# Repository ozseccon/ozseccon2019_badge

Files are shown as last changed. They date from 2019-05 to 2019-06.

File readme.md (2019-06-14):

# OzSecCon 2019 badge design.
designed in kicad v4
FW developed using (embedded rust)[https://rust-embedded.github.io].

# Instructions for use
## Using the badge
Bottom Button plays track
Top Button is to change track

Long press on Top to change card
Long press on Bottom to exit magspoof mode
(i was going to make a pattern thing appear but ran out of time)

## Loading new cards
card program is present at 
    ./ozseccon2019_utility/cardutil.py

Cards are formatted as a JSON file
Badge uses USB HID to communication.
i've only used ubuntu 14.04 to test so YMMV.

python libs used are:
hid
time
argparse
json

1. Leave battery in.
1. CAREFULLY insert a USB micro cable.
1. check that it enumerates
    \#lsusb
    004 Device 001: ID 1d6b:0003 Linux Foundation 3.0 root hub
    Bus 003 Device 107: ID ffff:ffff  
    Bus 003 Device 001: ID 1d6b:0002 Linux Foundation 2.0 root hub
you should see ID ffff:ffff show up.
1. run cardutil as root - this is due to using USB YMMV
```
    ozseccon2019_utility$ sudo python ./cardutil.py --cardfile ./carddata.json 
    ________             _________              _________                   
    \_____  \  ________ /   _____/  ____   ____ \_   ___ \   ____    ____   
     /   |   \ \___   / \_____  \ _/ __ \_/ ___\/    \  \/  /  _ \  /    \  
    /    |    \ /    /  /        \  ___/\  \___\     \____(  <_> )|   |  \ 
    \_______  //_____ \/_______  / \___  >\___  >\______  / \____/ |___|  / 
            \/       \/        \/      \/     \/        \/              \/  

    ________ _______   ____  ________  
    \_____  \   _  \ /_   |/   __   \ 
     /  ____//  /_\  \ |   |\____    / 
    /       \  \_/   \|   |   /    /  
    \_______ \_____  /|___|  /____/   
            \/      \/                 

    _________                     .___.____                       .___               
    \_   ___ \ _____  _______   __| _/|    |     ____ _____     __| _/ ____ _______  
    /    \  \/ \__  \ \_  __ \ / __ | |    |    /  _ \__  \   / __ |_/ __ \_  __ \ 
    \     \____ / __ \_|  | \// /_/ | |    |___(  <_> )/ __ \_/ /_/ |\  ___/ |  | \/ 
     \______  /(____  /|__|   \____ | |_______ \____/(____  /\____ | \___  >|__|    
            \/      \/             \/         \/           \/      \/     \/         
    usage: sudo python ./cardutil.py --cardfile [json formatted card file]
    [*] loading cards from ./carddata.json
    [*] loading card 1:
    [*] track1: %B4444444444444444^ABE/LINCOLN^291110100000931?D
    [*] track2: ;4444444444444444=29111010000093100000?9
    [*] track3: 000000000000000000000000000
    [*] loading card 2:
    [*] track1: %B1234567890123445^PADILLA/L.                ^9901120000000000000055123888888?~
    [*] track2: ;1234567890123445=99011200XXXX00000000?*
    [*] track3: ;011234567890123445=72472410000000000003030033040400099010=4320943290432==1=0000000000000000??
    [*] loading card 3:
    [*] track1: %B4888603170607238^Head/Potato^050510100000000001203191805191000000?
    [*] track2: ;4888603170607238=05051011203191805191?
    [*] track3: ;1337?
    Manufacturer: OzSecCon.
    Product: MagSpoof
    Serial No: 1.0.0
    Closing the device
    [*] finished

    ./ozseccon2019_utility/cardutil.py
```
1. You should now be able to use it.

## reprogramming.
Convert file using the (elf2dfuse utility)[https://github.com/majbthrd/elf2dfuse]

1. Short J3 to get device into bootloader mode
1. reset - you should see the two LEDS light up 
1. check that DFU mode, should see ID 0483:df11
    peter@peter-ThinkPad-X230:/media/peter/VM Images/ozseccon2019/ozseccon2019_badge$ lsusb
    Bus 003 Device 119: ID 0483:df11 STMicroelectronics STM Device in DFU Mode
1. check that dfu-util detects board
```
    ~/src/elf2dfuse$ sudo dfu-util -l
    enter sudo password 
    dfu-util 0.8
    
    Copyright 2005-2009 Weston Schmidt, Harald Welte and OpenMoko Inc.
    Copyright 2010-2014 Tormod Volden and Stefan Schmidt
    This program is Free Software and has ABSOLUTELY NO WARRANTY
    Please report bugs to dfu-util@lists.gnumonks.org
    
    Found DFU: [0483:df11] ver=2200, devnum=123, cfg=1, intf=0, alt=1, name="@Option Bytes  /0x1FFFF800/01*016 e", serial="FFFFFFFEFFFF"
    Found DFU: [0483:df11] ver=2200, devnum=123, cfg=1, intf=0, alt=0, name="@Internal Flash  /0x08000000/032*0001Kg", serial="FFFFFFFEFFFF"
    Found Runtime: [0a5c:21e6] ver=0112, devnum=4, cfg=1, intf=3, alt=0, name="UNKNOWN", serial="083E8EE37645"
```
1. use alt 0 - internal flash and program your DFU file
```
    ~/src/elf2dfuse$ sudo dfu-util -d 0483:df11 -a 0 -D ./final.dfu 
    dfu-util 0.8
    
    Copyright 2005-2009 Weston Schmidt, Harald Welte and OpenMoko Inc.
    Copyright 2010-2014 Tormod Volden and Stefan Schmidt
    This program is Free Software and has ABSOLUTELY NO WARRANTY
    Please report bugs to dfu-util@lists.gnumonks.org
    
    Opening DFU capable USB device...
    ID 0483:df11
    Run-time device DFU version 011a
    Claiming USB DFU Interface...
    Setting Alternate Setting #0 ...
    Determining device status: state = dfuERROR, status = 10
    dfuERROR, clearing status
    Determining device status: state = dfuIDLE, status = 0
    dfuIDLE, continuing
    DFU mode device DFU version 011a
    Device returned transfer size 2048
    DfuSe interface name: "Internal Flash  "
    file contains 1 DFU images
    parsing DFU image 1
    image for alternate setting 0, (2 elements, total size = 12780)
    parsing element 1, address = 0x08000000, size = 12052
    Download    [=========================] 100%        12052 bytes
    Download done.
    parsing element 2, address = 0x08002f20, size = 712
    Download    [=========================] 100%          712 bytes
    Download done.
    done parsing DfuSe file
 ```
 
# Stuff i stole/copied from to make this badge
[Samy Kamkar's Magspoof](http://samy.pl/magspoof/)

[RyscCorp's version](https://github.com/RyscCorp/magspoof_r3)

[Aleh Zasypkin Awesome Kroneum project](https://github.com/azasypkin/kroneum)

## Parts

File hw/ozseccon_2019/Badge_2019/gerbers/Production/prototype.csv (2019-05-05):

Id | Designator | Package | Quantity | Designation | Supplier and ref
1 | AE1 | Antenna | 1 | Antenna_Loop
2 | C1 | CP_Elec_6.3x5.7 | 1 | 100uF
3 | C2,C4,C5 | C_0805 | 3 | 100nF
4 | C3 | C_0805 | 1 | 10nF
5 | C6 | C_0805 | 1 | 1uF
6 | C7,C8 | C_0805 | 2 | 4.7uF
7 | D1 | LED_RGB_5050-6 | 1 | LED1
8 | D2 | LED_RGB_5050-6 | 1 | LED2
9 | J1 | BoldPort_Pin_Header_Straight_1x07_Pitch2.54mm | 1 | Conn_01x07_Female
10 | J2 | Pin_Header_Straight_1x04_Pitch2.54mm | 1 | SWD
11 | J3 | Pin_Header_Straight_1x02_Pitch2.54mm | 1 | BOOT0
12 | J4 | Pin_Header_Straight_1x02_Pitch2.54mm | 1 | nRST
13 | J5 | Pin_Header_Straight_2x05_Pitch2.54mm | 1 | LSAO
14 | J6 | USB_Micro-B_Molex-105017-0001 | 1 | USB_MICRO
15 | R1 | R_0805 | 1 | 10k
16 | R2,R3 | R_0805 | 2 | 22
17 | SW1,SW2 | TactSwitch | 2 | SW_DPST_OZSECCON
18 | U1 | ICC_FOOTPRINT | 1 | ICC_Pads
19 | U2 | SOIC-8_3.9x4.9mm_Pitch1.27mm | 1 | TC4424A
20 | U3 | OzSecCon_LQFP-48_7x7mm_Pitch0.5mm | 1 | STM32F042C6T6
21 | BT1 | Keystone_3034_1x20mm-CoinCell | 1 | Battery_Cell
22 | FID1,FID2,FID3 | Fiducial_0.5mm_Dia_1mm_Outer | 3 | Fiducial
23 |  | skully | 1
24 |  | Privasec | 1
25 | REF** | Board_Outline | 1 | Board_Outline

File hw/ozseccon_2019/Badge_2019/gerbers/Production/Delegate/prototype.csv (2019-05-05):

Id | Designator | Package | Quantity | Designation | Supplier and ref | Datasheet | Substitute with lower cost | Extra Components
1 | C1 | CP_Elec_6.3x5.7 | 1 | 100uF | MCVVT016M101EA1L | http://www.farnell.com/datasheets/2151198.pdf | Y | 30
2 | C2,C4,C5 | C_0805 | 3 | 100nF |  |  | Y | 30
3 | C3 | C_0805 | 1 | 10nF |  |  | Y | 30
4 | C6 | C_0805 | 1 | 1uF |  |  | Y | 30
5 | C7,C8 | C_0805 | 2 | 4.7uF |  |  | Y | 30
6 | D1, D2 | LED_RGB_5050-6 | 2 | Yuan Lei LED SMD 5050 RGB | Yuan Lei LED SMD 5050 RGB |  | Y | 30
7 | J6 | USB_Micro-B_Molex-105017-0001 | 1 | USB_MICRO | Multicomp MC001009/ USB Micro B |  | Y | 30
8 | R1 | R_0805 | 1 | 10k |  |  | Y | 30
9 | R2,R3 | R_0805 | 2 | 22 |  |  | Y | 30
10 | SW1,SW2 | TactSwitch | 2 | SW_DPST_OZSECCON | https://www.altronics.com.au/p/s1112a-spst-momentary-smd-4.3mm-tactile-switch/ |  | Y | 30
11 | U2 | SOIC-8_3.9x4.9mm_Pitch1.27mm | 1 | TC4424A | TC4424AVOA713 | http://www.farnell.com/datasheets/512945.pdf | N | 30
12 | U3 | OzSecCon_LQFP-48_7x7mm_Pitch0.5mm | 1 | STM32F042C6T6/STM32 48 pin LQFP, 32kb Flash, 6kb RAM | https://au.element14.com/stmicroelectronics/stm32f042c6t6/mcu-arm-cortex-m0-48mhz-lqfp-48/dp/2750630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 | http://www.farnell.com/datasheets/2281753.pdf | N | 30
13 | BT1 | Keystone_3034_1x20mm-CoinCell | 1 | Battery_Cell | 3034 - BATTERY CONTACT, COIN CELL, 20MM | https://au.element14.com/keystone/3034/battery-contact-coin-cell-20mm/dp/2959377?st=keystone%203034 | Y | 30

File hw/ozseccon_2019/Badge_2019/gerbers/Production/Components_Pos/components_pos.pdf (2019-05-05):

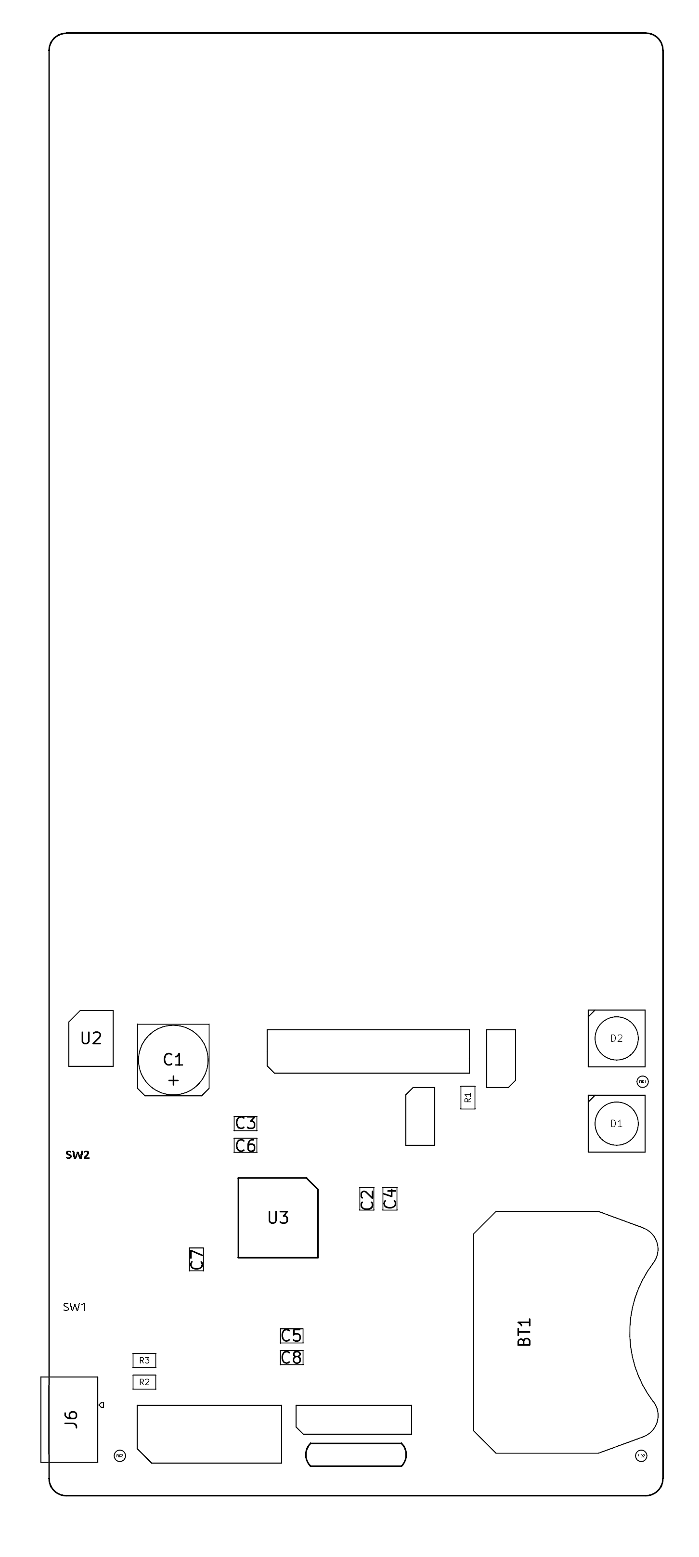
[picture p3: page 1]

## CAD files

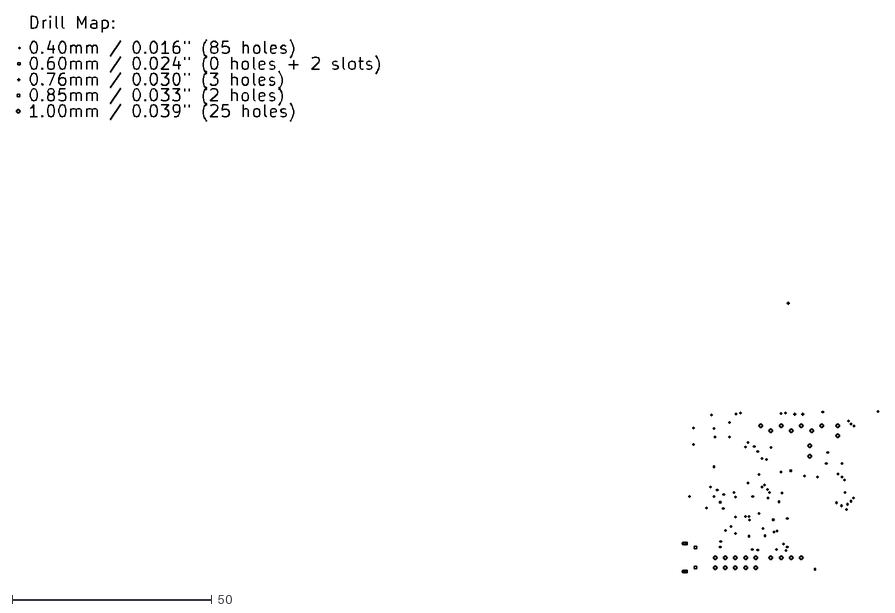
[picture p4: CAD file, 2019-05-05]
hw/ozseccon_2019/Badge_2019/gerbers/Production/Delegate/prototype-drl_map.dxf
216.0 x 139.3

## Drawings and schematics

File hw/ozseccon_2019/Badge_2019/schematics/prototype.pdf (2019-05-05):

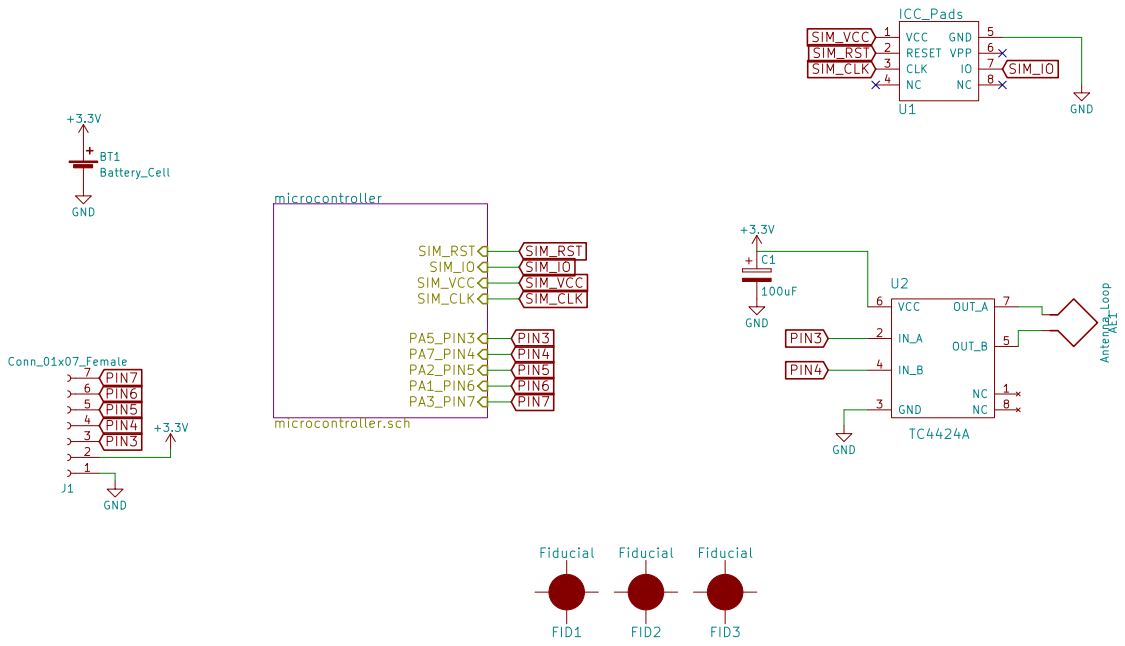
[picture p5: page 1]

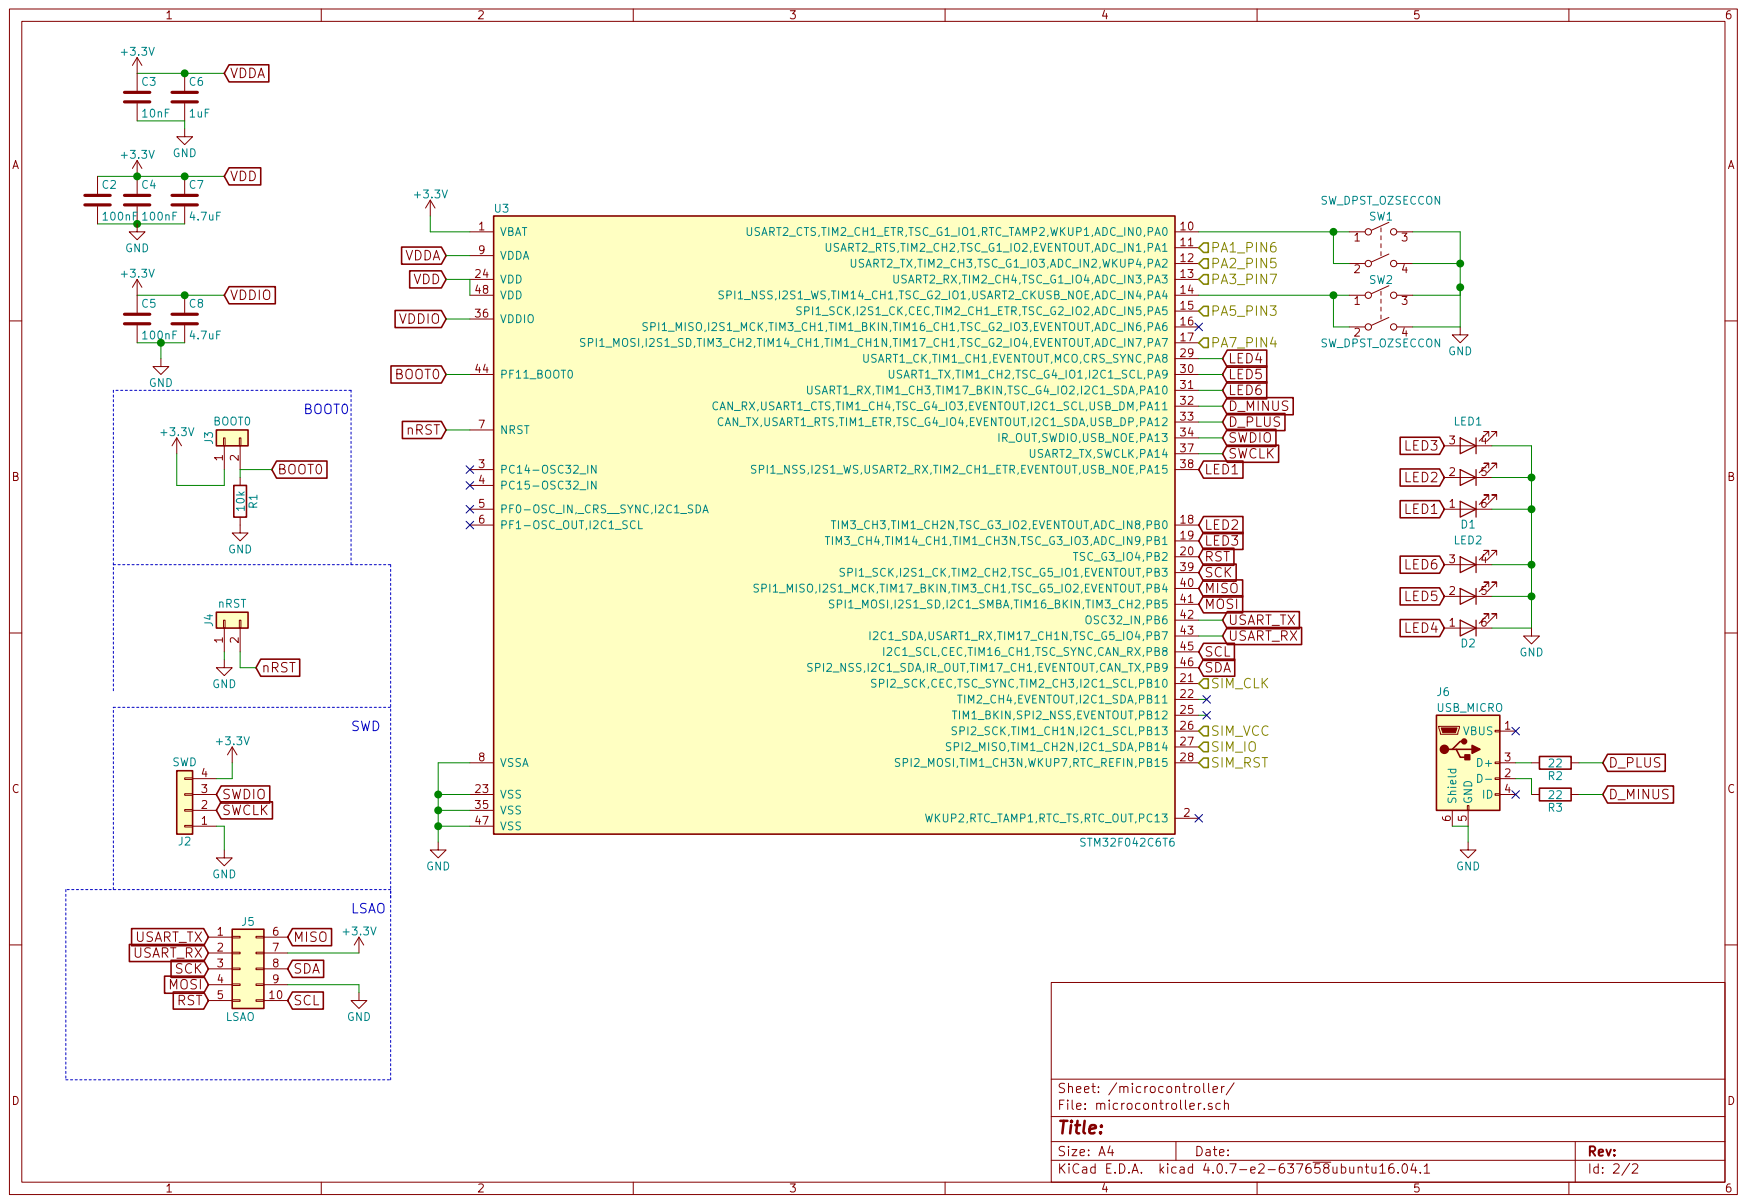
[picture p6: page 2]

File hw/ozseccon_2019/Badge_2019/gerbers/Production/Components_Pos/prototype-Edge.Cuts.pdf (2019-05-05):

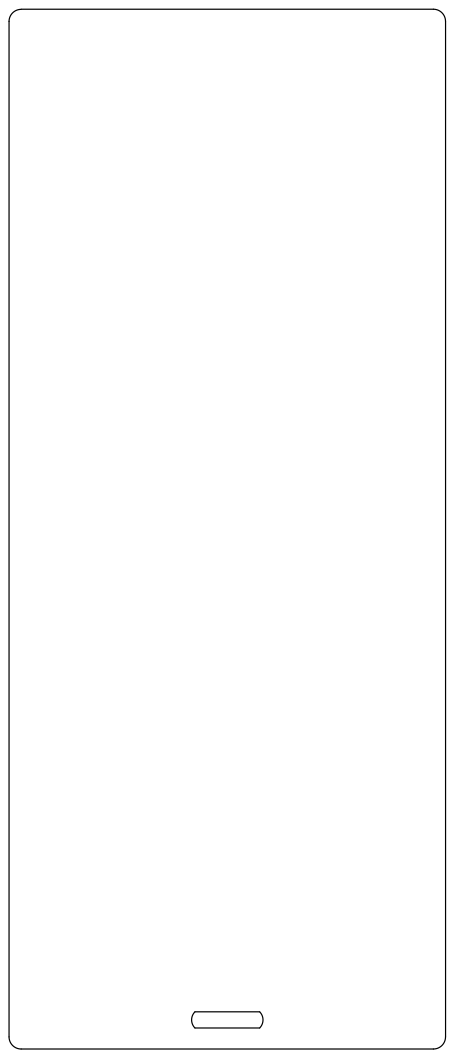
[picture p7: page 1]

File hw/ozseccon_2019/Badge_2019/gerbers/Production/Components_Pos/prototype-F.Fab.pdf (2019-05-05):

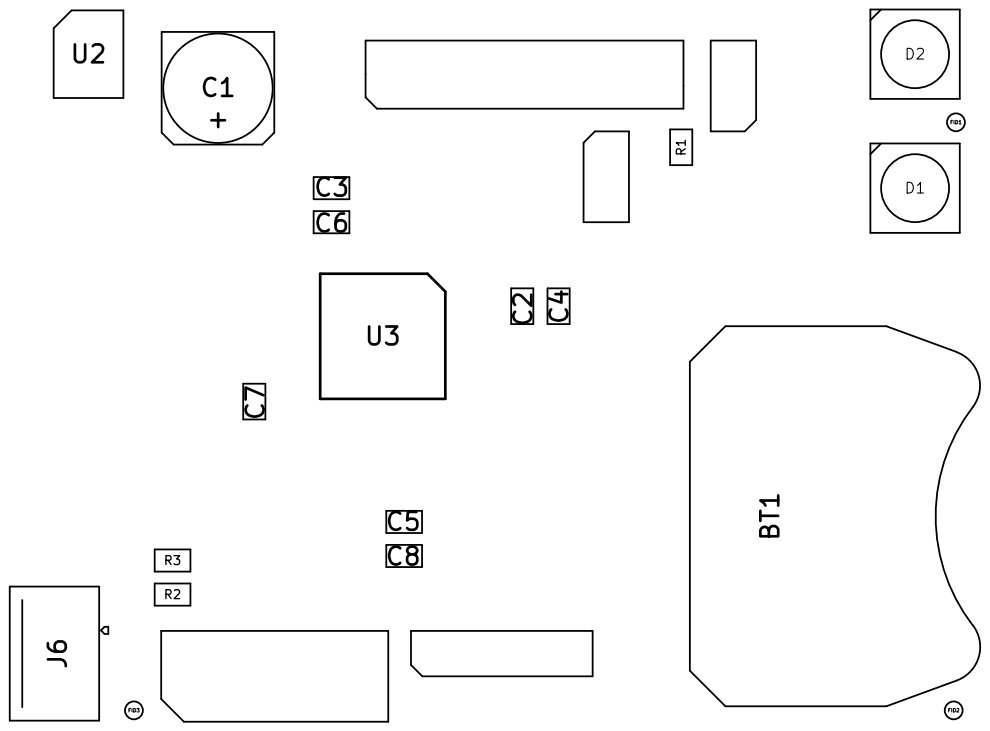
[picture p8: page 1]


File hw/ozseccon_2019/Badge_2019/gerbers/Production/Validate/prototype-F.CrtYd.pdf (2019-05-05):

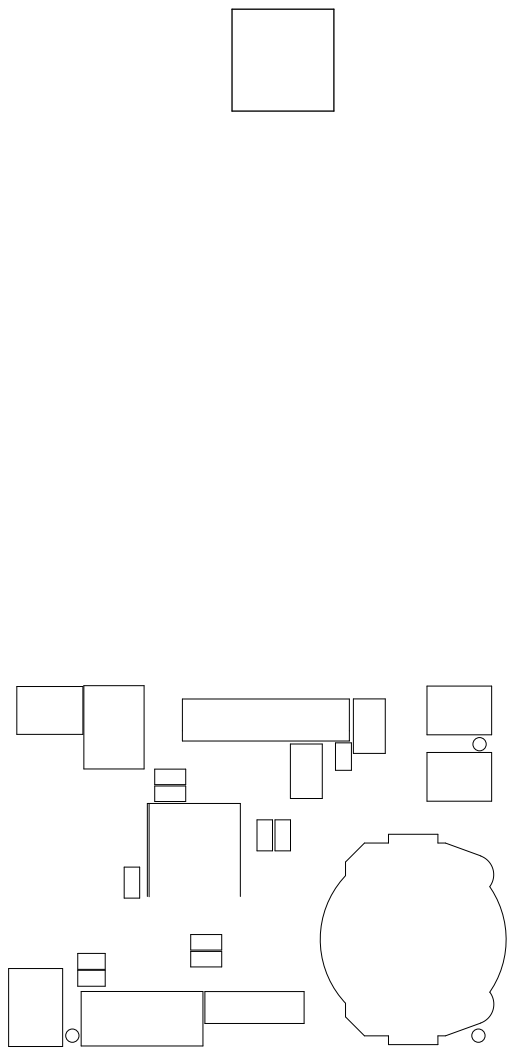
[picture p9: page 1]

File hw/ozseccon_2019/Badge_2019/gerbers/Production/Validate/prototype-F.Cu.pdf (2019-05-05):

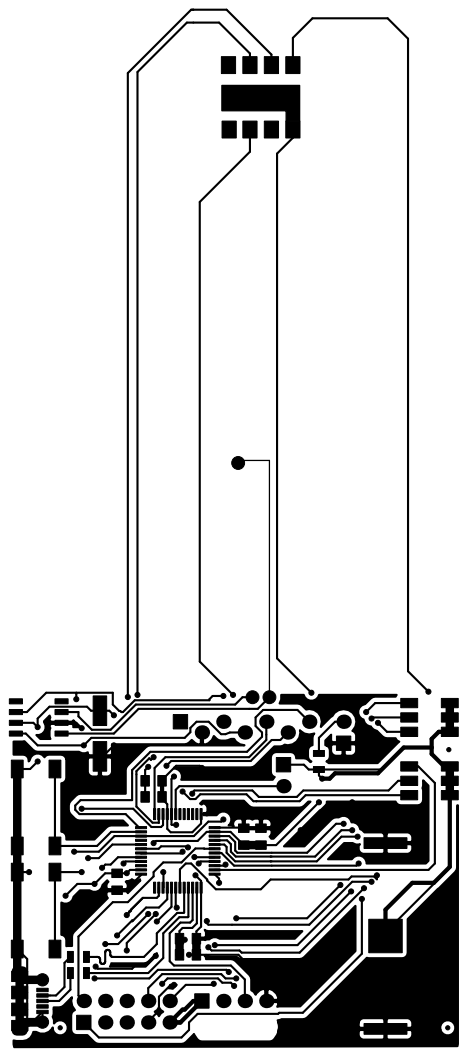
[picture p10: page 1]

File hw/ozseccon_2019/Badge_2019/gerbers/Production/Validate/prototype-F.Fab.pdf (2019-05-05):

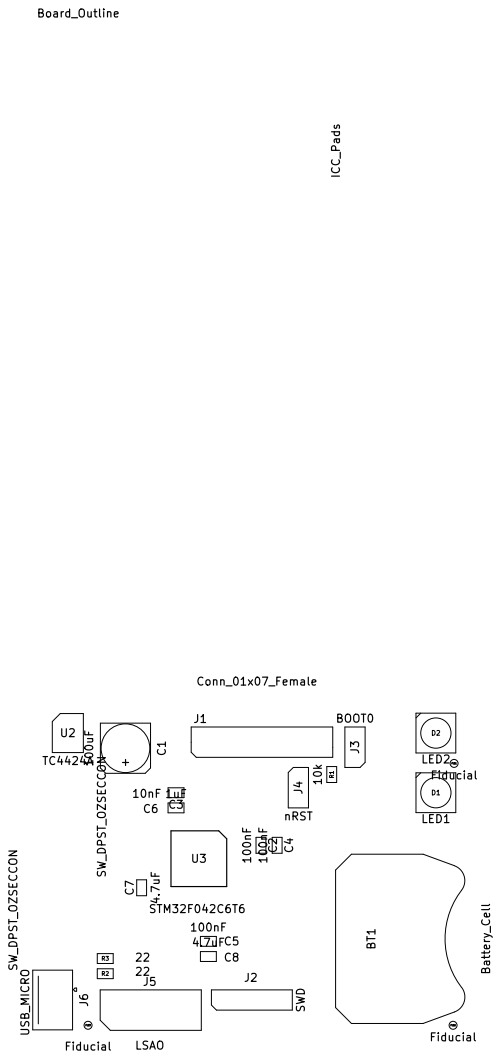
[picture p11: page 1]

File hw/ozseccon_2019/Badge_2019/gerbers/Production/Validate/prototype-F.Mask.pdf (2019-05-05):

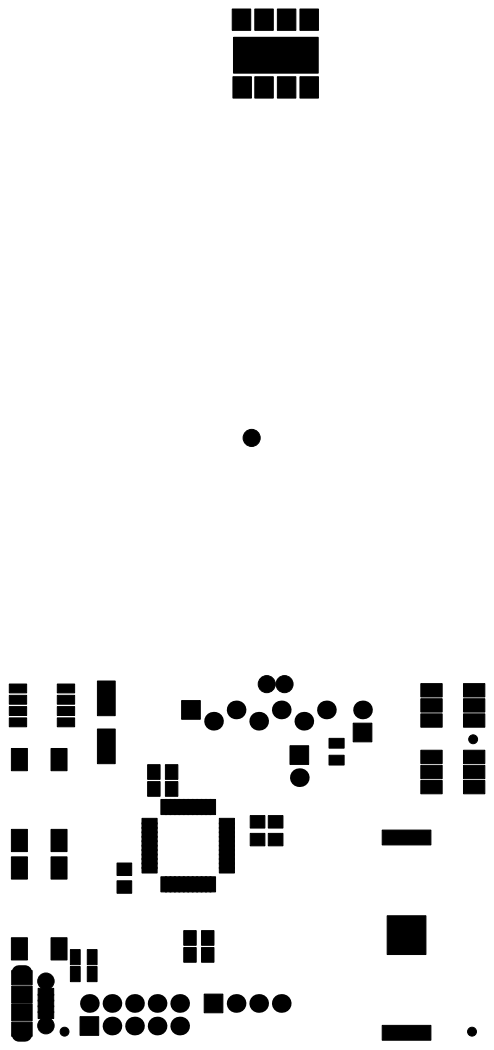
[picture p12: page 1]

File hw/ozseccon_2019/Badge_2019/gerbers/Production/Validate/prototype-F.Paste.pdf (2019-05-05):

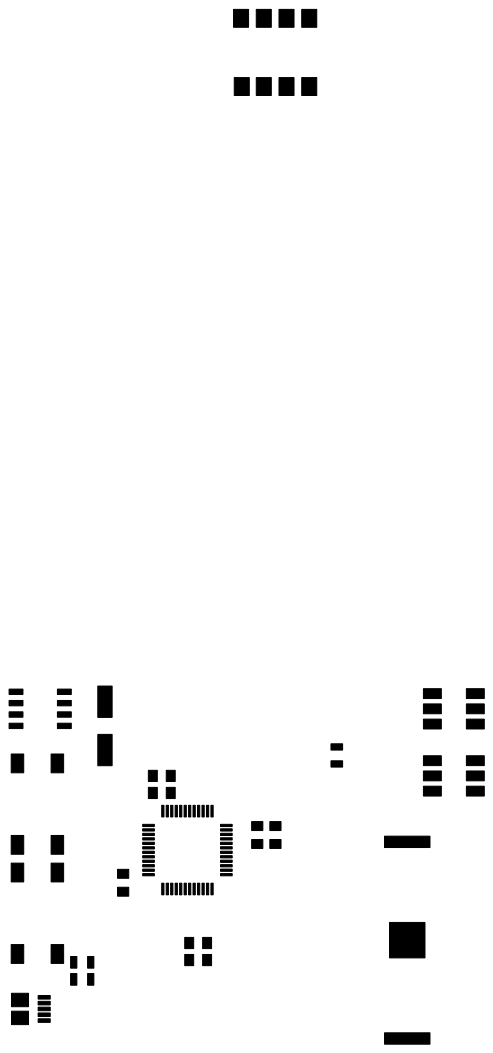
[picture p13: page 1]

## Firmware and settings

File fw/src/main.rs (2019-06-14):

#![no_std]
#![no_main]

#![allow(dead_code)]
#![allow(unused_variables)]
#![allow(unused_imports)]

// pick a panicking behavior
//extern crate panic_halt; // you can put a breakpoint on `rust_begin_unwind` to catch panics
//extern crate panic_semihosting; // you can put a breakpoint on `rust_begin_unwind` to catch panics
//extern crate panic_abort;

//use cortex_m_semihosting::hprintln;
// extern crate panic_abort; // requires nightly
// extern crate panic_itm; // logs messages over ITM; requires ITM support
//extern crate panic_semihosting; // logs messages to the host stderr; requires a debugger

//use cortex_m::asm;
use cortex_m_rt::{entry, exception, ExceptionFrame};
//use cortex_m;
//use cortex_m::{interrupt::Mutex};
//use cortex_m::{interrupt, Interrupt};

//extern crate stm32f0xx_hal;

//use stm32f0xx_hal as hal;
//use stm32f0xx_hal::stm32 as stm32;

use stm32f0xx_hal as hal;
//use stm32f0::stm32f0x0;

//use crate::hal::{prelude::*, stm32};

//use stm32f0xx_hal::stm32f0::u
use crate::hal::{
    prelude::*,
    rcc::*, 
    //spi::Spi,
    gpio::*,
    time::*,
    timers::*,
    delay::Delay, 
    stm32,
    stm32::Interrupt,//device
    //interrupt,
};
use nb::block;

use crate::hal::stm32::interrupt;
use stm32f0xx_hal::stm32::Interrupt::EXTI0_1;

use cortex_m::{interrupt::Mutex, peripheral::syst::SystClkSource::Core, Peripherals};

use core::cell::RefCell;
use core::ops::DerefMut;

//pub mod ozsecconusb;
pub mod usb;
use usb::systick::*;
use usb::system::*;

//pub mod systick;
//pub mod system;

//static LED1_BLUE: Mutex<RefCell<Option<gpioa::PA8<Output<PushPull>>>>> = Mutex::new(RefCell::new(None));
//static LED1_RED: Mutex<RefCell<Option<gpioa::PA9<Output<PushPull>>>>> = Mutex::new(RefCell::new(None));
//static LED1_GREEN: Mutex<RefCell<Option<gpioa::PA10<Output<PushPull>>>>> = Mutex::new(RefCell::new(None));
//
//static LED2_BLUE: Mutex<RefCell<Option<gpioa::PA15<Output<PushPull>>>>> = Mutex::new(RefCell::new(None));
//static LED2_RED: Mutex<RefCell<Option<gpiob::PB3<Output<PushPull>>>>> = Mutex::new(RefCell::new(None));
//static LED2_GREEN: Mutex<RefCell<Option<gpiob::PB10<Output<PushPull>>>>> = Mutex::new(RefCell::new(None));

//teeth
//static TOOTH_1: Mutex<RefCell<Option<gpiob::PB11<Output<PushPull>>>>> = Mutex::new(RefCell::new(None));
//static TOOTH_2: Mutex<RefCell<Option<gpiob::PB12<Output<PushPull>>>>> = Mutex::new(RefCell::new(None));
//static TOOTH_3: Mutex<RefCell<Option<gpiob::PB13<Output<PushPull>>>>> = Mutex::new(RefCell::new(None));
//static TOOTH_4: Mutex<RefCell<Option<gpiob::PB14<Output<PushPull>>>>> = Mutex::new(RefCell::new(None));
//static TOOTH_5: Mutex<RefCell<Option<gpiob::PB15<Output<PushPull>>>>> = Mutex::new(RefCell::new(None));

static MYEXTI: Mutex<RefCell<Option<stm32f0xx_hal::stm32::EXTI>>> = Mutex::new(RefCell::new(None));

static TIMER: Mutex<RefCell<Option<stm32f0xx_hal::timers::Timer<stm32f0xx_hal::stm32::TIM2>>>> = Mutex::new(RefCell::new(None));

static SYSTEM: Mutex<RefCell<Option<System<SystickHardwareImpl>>>> = Mutex::new(RefCell::new(None));

#[entry]
fn main() -> ! {
    let mut cp = stm32::CorePeripherals::take().unwrap();
    let mut dp = stm32::Peripherals::take().unwrap();
    //let syscfg = dp.SYSCFG; 
    //let mut nvic = &cp.NVIC;
    //let exti = &dp.EXTI; 
    
    //USB config  
    //dp.RCC.apb2enr.modify(|_, w| w.syscfgen().set_bit());
    //// Remap PA9-10 to PA11-12 for USB.
    //syscfg 
    //    .cfgr1
    //    .modify(|_, w| w.pa11_pa12_rmp().set_bit().mem_mode().main_flash());
    
    //let mut rcc = dp.RCC.configure().sysclk(48.mhz()).freeze(&mut dp.FLASH);
    //let mut clocks = rcc.clocks;
    //let rcc = dp.RCC.constrain();
    //let rcc = dp.RCC;
    //let clocks = rcc.cfgr.sysclk(8.mhz()).freeze();
    //let delay = Delay::new(cp.SYST, &mut rcc);
    //let timer2  = Timer::tim2(dp.TIM2, Hertz(1), &mut rcc);
    
    //let gpioa = dp.GPIOA.split(&mut rcc);
    //let gpiob = dp.GPIOB.split(&mut rcc);
     
    //cortex_m::interrupt::free(move |cs| { 
    cortex_m::interrupt::free(|cs| { 
        
        let mut system = System::new(
            dp,
            usb::systick::create(cp.SYST),
            cp.SCB,
        );
        system.setup();

        *SYSTEM.borrow(cs).borrow_mut() = Some(system); 
       
        cp.NVIC.enable(Interrupt::EXTI0_1); 
        cp.NVIC.enable(Interrupt::EXTI4_15); 
        cp.NVIC.enable(Interrupt::USB); 
        //let led1blue = gpioa.pa8.into_push_pull_output(cs);
        //let led1red = gpioa.pa9.into_push_pull_output(cs);
        //let led1green = gpioa.pa10.into_push_pull_output(cs);
        //  
        //let led2blue =  gpioa.pa15.into_push_pull_output(cs);
        //let led2red =  gpiob.pb3.into_push_pull_output(cs);
        //let led2green = gpiob.pb10.into_push_pull_output(cs);
        //
        //*LED1_BLUE.borrow(cs).borrow_mut() = Some(led1blue);
        //*LED1_RED.borrow(cs).borrow_mut() = Some(led1red);
        //*LED1_GREEN.borrow(cs).borrow_mut() = Some(led1green);
       
        //*LED2_BLUE.borrow(cs).borrow_mut() = Some(led2blue);
        //*LED2_RED.borrow(cs).borrow_mut() = Some(led2red);
        //*LED2_GREEN.borrow(cs).borrow_mut() = Some(led2green);
 
        //setup switch 1 
        //syscfg.exticr1.modify(|_, w| unsafe{ w.exti0().bits(0b000)});
        //setup switch 2 
        //syscfg.exticr2.modify(|_, w| unsafe{ w.exti4().bits(0b000)});
        //exti.ftsr.modify(|_,w|  w.tr0().set_bit().tr4().set_bit());
        //exti.rtsr.modify(|_,w|  w.tr0().clear_bit().tr4().clear_bit());
        //exti.imr.modify(|_,w|  w.mr0().set_bit().mr4().set_bit());
        //unsafe{nvic.set_priority(Interrupt::EXTI0_1, 1);} 
        //unsafe{nvic.set_priority(Interrupt::EXTI4_15, 1);} 
        //nvic.enable(Interrupt::EXTI0_1); 
        //nvic.enable(Interrupt::EXTI4_15); 
        //*MYEXTI.borrow(cs).borrow_mut() = Some(exti);
        //*TIMER.borrow(cs).borrow_mut() = Some(timer2);
    
        //setup USB
        // Set "high" output speed for PA11 and PA12.
        //let _ = gpioa.pa11.into_push_pull_output_hs(cs).into_alternate_af2(cs);
        //let _ = gpioa.pa12.into_push_pull_output_hs(cs).into_alternate_af2(cs);
        //nvic.enable(Interrupt::USB); 
    });
 
    loop {
        cortex_m::asm::wfi(); 
        //if switch2.is_low() { 
        //    mymagspoof.play_card(&mycard);
        //    led2red.set_high(); 
        //    block!(timer2.wait()).ok();
        //    led2red.set_low(); 
        //}        //continue;
    }
}

//#[interrupt]
//fn EXTI0_1()
//{
//    let trk1 = "%B4444444444444444^ABE/LINCOLN^291110100000931?";
//    let trk2 = ";4444444444444444=29111010000093100000?";
//    //let track2 = ";12=34?";
//    let trk3 = "";
//
//    let mycard = magspoof::card{
//        track1: &trk1.as_bytes(), 
//        track2: &trk2.as_bytes(),
//        track3: &trk3.as_bytes(), 
//    };    
//    cortex_m::interrupt::free(|cs| {
//        //let Some(ref mut magspoof) = *MAGSPOOF.borrow(cs).borrow_mut().deref_mut(); 
//        if let Some(ref mut exti) = *MYEXTI.borrow(cs).borrow_mut().deref_mut() {
//            if exti.imr.read().mr0().bit_is_set() && exti.pr.read().pif0().bit_is_set() {  
//                if let Some(ref mut led1blue) = *LED1_BLUE.borrow(cs).borrow_mut().deref_mut() {
//                    led1blue.toggle(); 
//                }
//                if let Some(ref mut magspoof) = *MAGSPOOF.borrow(cs).borrow_mut().deref_mut() {
//                    magspoof.play_track(&mycard,2); 
//                }
//                if let Some(ref mut timer) = *TIMER.borrow(cs).borrow_mut().deref_mut() {
//                    block!(timer.wait()).ok();
//                }
//                if let Some(ref mut led1blue) = *LED1_BLUE.borrow(cs).borrow_mut().deref_mut() {
//                    led1blue.toggle(); 
//                }
//                exti.pr.modify(|_,w| w.pif0().set_bit());
//        } 
//        } 
//    });
//    cortex_m::peripheral::NVIC::unpend(Interrupt::EXTI0_1);
//}

//#[interrupt]
//fn EXTI4_15()
//{
//    let trk1 = "%B4444444444444444^ABE/LINCOLN^291110100000931?";
//    let trk2 = ";4444444444444444=29111010000093100000?";
//    //let track2 = ";12=34?";
//    let trk3 = "";
//
//    let mycard = magspoof::card{
//        track1: &trk1.as_bytes(), 
//        track2: &trk2.as_bytes(),
//        track3: &trk3.as_bytes(), 
//    };
//    cortex_m::interrupt::free(|cs| {
//        if let Some(ref mut exti) = *MYEXTI.borrow(cs).borrow_mut().deref_mut() {
//            if exti.imr.read().mr4().bit_is_set() && exti.pr.read().pif4().bit_is_set() {  
//                if let Some(ref mut led1red) = *LED1_RED.borrow(cs).borrow_mut().deref_mut() {
//                        led1red.toggle(); 
//                    }
//                if let Some(ref mut magspoof) = *MAGSPOOF.borrow(cs).borrow_mut().deref_mut() {
//                    magspoof.play_track(&mycard, 1); 
//                }
//                if let Some(ref mut timer) = *TIMER.borrow(cs).borrow_mut().deref_mut() {
//                    block!(timer.wait()).ok();
//                }
//                if let Some(ref mut led1red) = *LED1_RED.borrow(cs).borrow_mut().deref_mut() {
//                    led1red.toggle(); 
//                } 
//            exti.pr.modify(|_,w| w.pif4().set_bit());
//        } 
//        } 
//    });
//    cortex_m::peripheral::NVIC::unpend(Interrupt::EXTI4_15);
//}

#[interrupt]
fn USB() {
    interrupt_free(|system| system.on_usb_packet());
}

#[interrupt]
fn EXTI0_1() {
    interrupt_free(|system| system.on_button_press());
}

#[interrupt]
fn EXTI4_15() {
    interrupt_free(|system| system.on_button_press());
}

#[exception]
fn DefaultHandler(irqn: i16) {
    panic!("unhandled exception (IRQn={})", irqn);
}

#[exception]
fn HardFault(_ef: &ExceptionFrame) -> ! {
    panic!("hard fault (PC={})", _ef.pc);
}

fn interrupt_free<F>(f: F)
where
    F: FnOnce(&mut usb::system::System<usb::systick::SystickHardwareImpl>),
{
    cortex_m::interrupt::free(|cs| {
        if let Some(s) = SYSTEM.borrow(cs).borrow_mut().as_mut() {
            f(s);
        } else {
            panic!("Can not borrow application state!");
        }
    });
}

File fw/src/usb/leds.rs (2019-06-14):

use crate::{SysTick, SysTickHardware};
use cortex_m::interrupt::free;
use stm32f0xx_hal as hal;
use crate::hal::{stm32::Peripherals,gpio::gpioa,gpio::gpiob,gpio::Output, gpio::PushPull, stm32::GPIOA, stm32::GPIOB, gpio::GpioExt, rcc::RccExt, stm32::RCC};
//use stm32f0::stm32f0x2::{Peripherals,gpioa,gpiob};

/// Describes the Buttons hardware management interface.
pub trait LedsHardware {
    fn setup(&self);
    fn setup_pwm(&self); //swap leds to PWM mode 
    fn teardown(&self);
    
    fn turnonLED1(&self); 
    fn turnoffLED1(&self); 
    fn toggleLED1(&self); 
    
    fn turnonLED2(&self); 
    fn turnoffLED2(&self); 
    fn toggleLED2(&self); 
    
    fn turnonLED3(&self); 
    fn turnoffLED3(&self); 
    fn toggleLED3(&self); 

    fn turnonLED4(&self); 
    fn turnoffLED4(&self); 
    fn toggleLED4(&self); 
    
    fn turnonLED5(&self); 
    fn turnoffLED5(&self); 
    fn toggleLED5(&self); 
    
    fn turnonLED6(&self); 
    fn turnoffLED6(&self); 
    fn toggleLED6(&self); 

    fn disable_LED4(&mut self);
    fn enable_LED4(&mut self);
    fn get_duty_LED4(&self) -> u16;
    fn get_max_duty_LED4(&self) -> u16;
    fn set_duty_LED4(&mut self, duty: u16); 
 
}

pub struct Leds <'a, T: LedsHardware, S: SysTickHardware> {
    hw: T,
    systick: &'a mut SysTick<S>,
}

impl<'a, T: LedsHardware, S: SysTickHardware> Leds<'a, T, S> {
    pub fn new(hw: T, systick: &'a mut SysTick<S>) -> Self {
        Leds { hw, systick,}
    }

    /// Setups Buttons hardware.
    pub fn setup(&self) {
        self.hw.setup();
    }
    
    pub fn setup_pwm(&self) {
        self.hw.setup_pwm();
    }
    /// Tears down Buttons hardware.
    pub fn teardown(&self) {
        self.hw.teardown();
    }

    pub fn turnonLED1(&self) {
        self.hw.turnonLED1(); 
    }

    pub fn turnoffLED1(&self) {
        self.hw.turnoffLED1(); 
    }
    
    pub fn toggleLED1(&self) {
        self.hw.toggleLED1(); 
    }

    pub fn turnonLED2(&self) {
        self.hw.turnonLED2(); 
    }

    pub fn turnoffLED2(&self) {
        self.hw.turnoffLED2(); 
    }
    pub fn toggleLED2(&self) {
        self.hw.toggleLED2();
    }

    pub fn turnonLED3(&self) {
        self.hw.turnonLED3(); 
    }

    pub fn turnoffLED3(&self) {
        self.hw.turnoffLED3(); 
    }
    pub fn toggleLED3(&self) {
        self.hw.toggleLED3();
    }
    
    pub fn turnonLED4(&self) {
        self.hw.turnonLED4(); 
    }

    pub fn turnoffLED4(&self) {
        self.hw.turnoffLED4(); 
    }
    pub fn toggleLED4(&self) {
        self.hw.toggleLED4(); 
    }

    pub fn turnonLED5(&self) {
        self.hw.turnonLED5(); 
    }

    pub fn turnoffLED5(&self) {
        self.hw.turnoffLED5(); 
    }
    pub fn toggleLED5(&self) {
        self.hw.toggleLED5(); 
    }

    pub fn turnonLED6(&self) {
        self.hw.turnonLED6(); 
    }

    pub fn turnoffLED6(&self) {
        self.hw.turnoffLED6(); 
    }
    pub fn toggleLED6(&self) {
        self.hw.toggleLED6(); 
    }

    pub fn disable_LED4(& mut self) {
        self.hw.disable_LED4(); 
    }
    
    pub fn enable_LED4(& mut self) {
        self.hw.enable_LED4(); 
    } 
    pub fn get_duty_LED4(&self) -> u16 {
        self.hw.get_duty_LED4() 
    }
    pub fn get_max_duty_LED4(&self) -> u16 {
        self.hw.get_max_duty_LED4() 
    }
    pub fn set_duty_LED4(& mut self, duty: u16) {
        self.hw.set_duty_LED4(duty);
    } 
}

pub struct LedsHardwareImpl<'a> {
    p: &'a Peripherals,
}

impl<'a> LedsHardware for LedsHardwareImpl<'a> {
    fn setup(&self) {
        //config GPIOs 
        self.p.GPIOA.moder.modify(|_, w| {
                w.moder8().output()         
                 .moder9().output()         
                 .moder10().output()         
                 .moder15().output()         
            });   
        self.p.GPIOB.moder.modify(|_, w| {
                w.moder0().output()         
                 .moder1().output()         
            });   
    }
    
    fn setup_pwm(&self){ //swap leds to PWM mode 
        //LED4 - TIM1_CH1 - AF2
        //LED5 - TIM1_CH2 - AF2
        //LED6 - TIM1_CH3 - AF2
        //LED1 - TIM2_CH1_ETR - AF2
        //LED2 - TIM3_CH3 - AF1
        //LED3 - TIM3_CH4 - AF1
        //config GPIOs 
        //enable pupds 
        self.p.GPIOA.pupdr.modify(|_, w| {
                w.pupdr8().pull_up()         
                 .pupdr9().pull_up()         
                 .pupdr10().pull_up()         
                 .pupdr15().pull_up()         
            });   
        self.p.GPIOB.pupdr.modify(|_, w| {
                w.pupdr0().pull_up()         
                 .pupdr1().pull_up()         
            });   
        //leds into alternate mode 
        self.p.GPIOA.moder.modify(|_, w| {
                w.moder8().alternate()         
                 .moder9().alternate()         
                 .moder10().alternate()         
                 .moder15().alternate()         
            });   
        self.p.GPIOB.moder.modify(|_, w| {
                w.moder0().alternate()         
                 .moder1().alternate()         
            });   
        //set alternate functions 
        self.p.GPIOA.afrh.modify(|_, w| {
                w.afrh8().af2()         
                 .afrh9().af2()         
                 .afrh10().af2()         
                 .afrh15().af2()         
            });   
        self.p.GPIOB.afrl.modify(|_, w| {
                w.afrl0().af1()         
                 .afrl1().af1()         
            });   
        
        //enable timer 1 
        self.p.RCC.apb2enr.modify(|_, w| w.tim1en().set_bit());
        self.p.RCC.apb2rstr.modify(|_, w| w.tim1rst().reset());
        //self.RCC.apb2rstr.modify(|_, w| w.tim1rst().set_bit());
        //self.RCC.apb2rstr.modify(|_, w| w.tim1rst().clear_bit());
        self.p.TIM1.ccmr1_output.modify(|_, w| unsafe { w.oc1pe().set_bit().oc1m().bits(6) });
        self.p.TIM1.ccmr1_output.modify(|_, w| unsafe { w.oc2pe().set_bit().oc2m().bits(6) });
        self.p.TIM1.ccmr2_output.modify(|_, w| unsafe { w.oc3pe().set_bit().oc3m().bits(6) });
       
        //enable timer 2  
        self.p.RCC.apb1enr.modify(|_, w| w.tim2en().set_bit());
        self.p.RCC.apb1rstr.modify(|_, w| w.tim2rst().reset());
        //self.RCC.apb2rstr.modify(|_, w| w.tim1rst().set_bit());
        //self.RCC.apb2rstr.modify(|_, w| w.tim1rst().clear_bit());
        self.p.TIM2.ccmr1_output.modify(|_, w| unsafe { w.oc1pe().set_bit().oc1m().bits(6) });

        //enable timer 3
        self.p.RCC.apb1enr.modify(|_, w| w.tim3en().set_bit());
        self.p.RCC.apb1rstr.modify(|_, w| w.tim3rst().reset());
        self.p.TIM3.ccmr2_output.modify(|_, w| unsafe { w.oc3pe().set_bit().oc3m().bits(6) });
        self.p.TIM3.ccmr2_output.modify(|_, w| unsafe { w.oc3pe().set_bit().oc3m().bits(6) });
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
